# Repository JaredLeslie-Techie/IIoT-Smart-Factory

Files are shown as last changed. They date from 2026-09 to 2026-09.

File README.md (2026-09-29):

# IIoT Smart Factory

An Industrial Internet of Things project connecting a physical ESP8266 plant to MQTT, Node-RED dashboards, and a browser-based factory simulation. The physical setup reads environmental sensors, handles local controls, drives a DC motor, and indicates robot state with two LEDs.

## System overview

```mermaid
flowchart TB
    HW["ESP8266: sensors, buttons, motor, LEDs"]
    MQ["HiveMQ Cloud MQTT broker"]
    NR["Node-RED monitoring dashboards"]
    SIM["Browser factory simulation"]

    HW <-->|"MQTT over TLS"| MQ
    MQ -->|"Telemetry and state"| NR
    SIM <-->|"MQTT over WebSocket"| MQ
```

The firmware publishes measurements and button/state events. The browser simulation can publish remote commands to the broker. The supplied Node-RED export subscribes to MQTT messages and displays them; it contains no MQTT output node.

## Hardware

| Component | Purpose |
|---|---|
| NodeMCU ESP8266 | Wi-Fi controller and MQTT client |
| DHT11 | Temperature and humidity |
| LDR module | Light intensity |
| Four push buttons | Local robot and conveyor Start/Stop |
| L298N and DC motor | Conveyor drive |
| Yellow and blue LEDs | Robot operating and idle indication |
| Raspberry Pi 4 | Node-RED host used for the project |

| ESP8266 pin | Connection |
|---|---|
| D0 / D1 | L298N motor inputs |
| D2 / D3 | Conveyor Start / Stop buttons |
| D4 / D5 | Robot Start / Stop buttons |
| D6 / D7 | Yellow robot-on / blue robot-off LEDs |
| D8 | DHT11 |
| A0 | LDR |

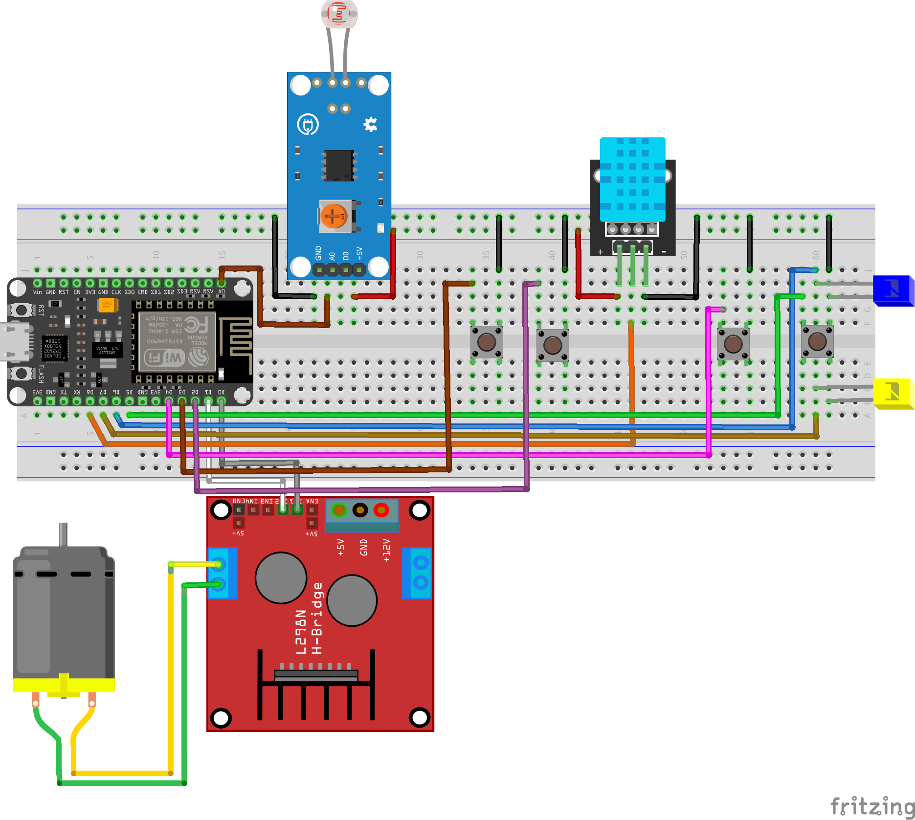
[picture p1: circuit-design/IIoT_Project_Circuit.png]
Fritzing circuit diagram


The complete editable Fritzing design and a PDF are in [`circuit-design/`](circuit-design/). The detailed pin table, flowcharts, and implementation notes are in the [technical notebook](documentation/IIoT_Smart_Factory_Documentation.ipynb).

## MQTT topics

The firmware publishes the following topics. Temperature, humidity, light intensity, and motor state are sent at a two-second interval; button events are sent when pressed.

| Topic | Value |
|---|---|
| `room/temperature` | Temperature in °C |
| `room/humidity` | Relative humidity in % |
| `room/LightIntensity` | Mapped light level, 0–100 |
| `room/MotorState` | `1` running, `0` stopped |
| `room/StartButton`, `room/StopButton` | Physical conveyor button events |
| `room/StartRobot`, `room/StopRobot` | Robot control events and status |

The firmware subscribes to these active command topics. It accepts `1`, `true`, `on`, `start`, or `pressed` as an active payload.

| Topic | Physical effect |
|---|---|
| `factory/room1/robot/start` | Yellow LED on, blue LED off |
| `factory/room1/robot/stop` | Yellow LED off, blue LED on |
| `room/StartButton` | Start the conveyor motor |
| `room/StopButton` | Stop the conveyor motor |

The Node-RED flow also **monitors** `factory/room1/conveyor/start` and `factory/room1/conveyor/stop` to update its dashboard state. It does not translate those messages into commands for the ESP8266. To control the physical conveyor, a remote client must publish to the `room/StartButton` and `room/StopButton` topics used by the firmware.

## Dashboard and project evidence

The Node-RED export has **Smart Factory**, **Actuators and Sensors**, and **Weather** pages. The Weather flow obtains external observations and alerts through the Bright Sky API and compares them with local DHT11 readings. Its ten-minute risk estimate is based on weather variables and alert conditions.

| Smart Factory monitoring | Sensors and actuators | Weather page |
|---|---|---|
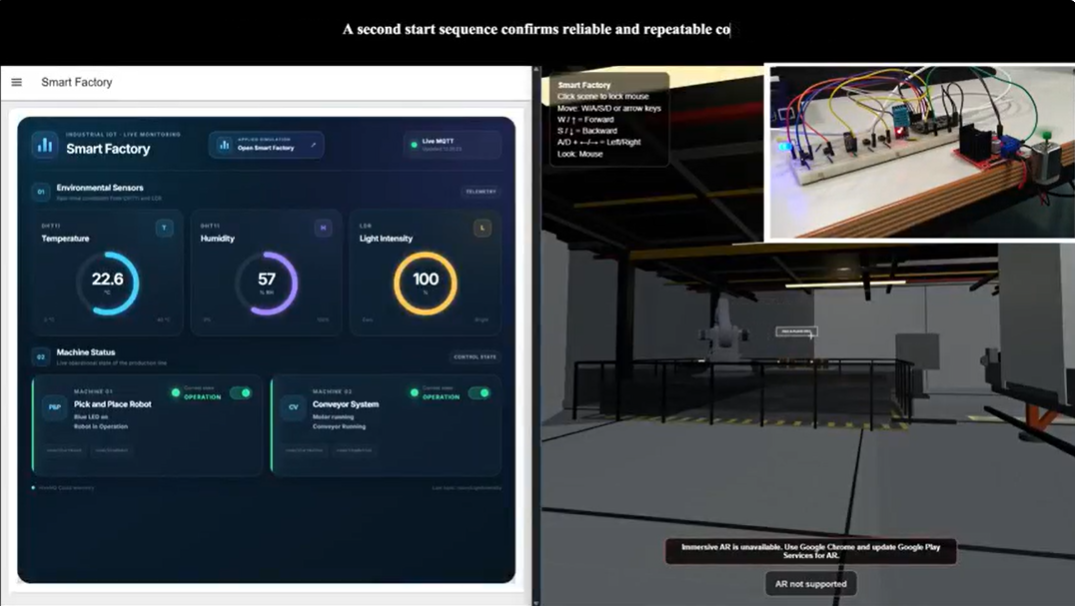
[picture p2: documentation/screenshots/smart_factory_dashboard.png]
Smart Factory dashboard
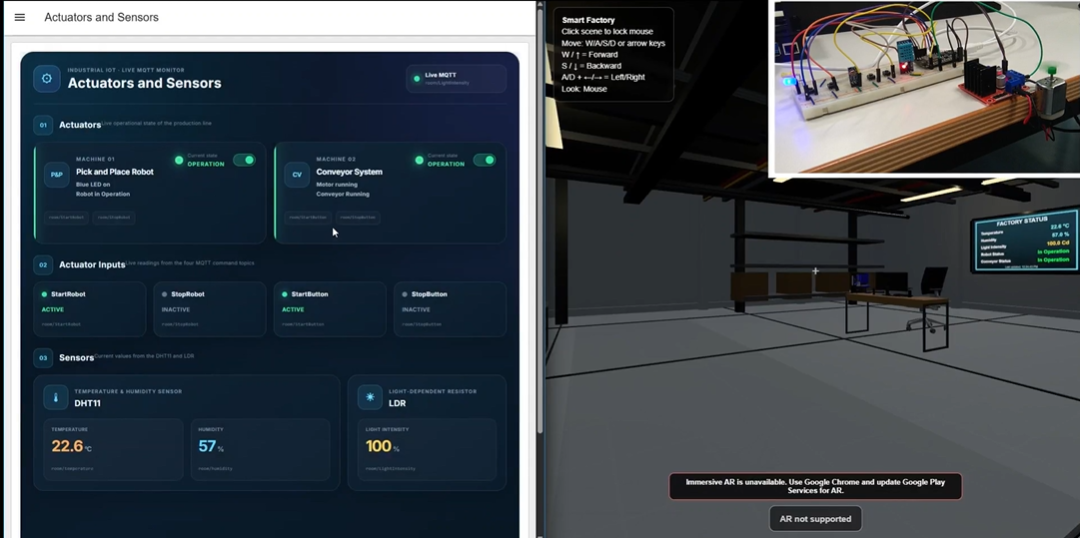
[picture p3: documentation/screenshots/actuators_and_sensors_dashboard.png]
Actuators and Sensors dashboard
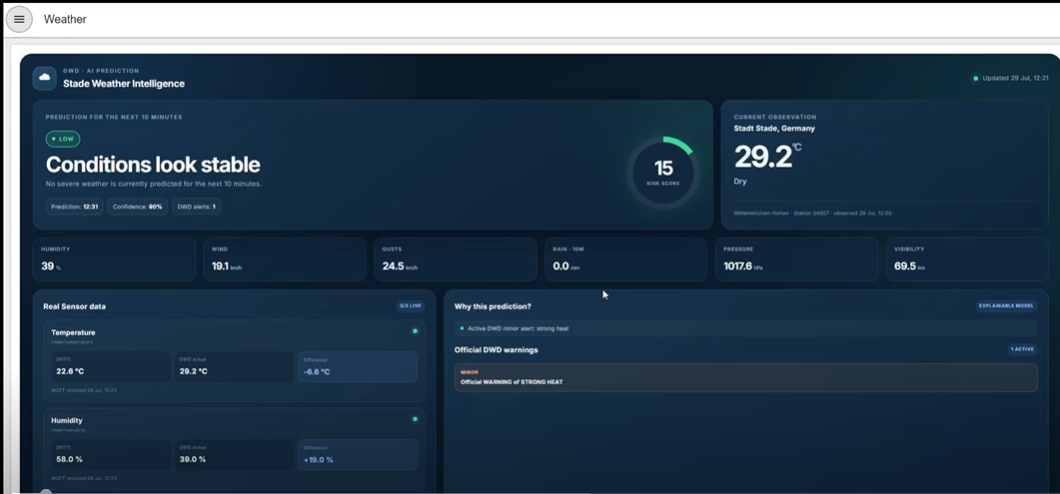
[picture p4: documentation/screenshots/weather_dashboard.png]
Weather dashboard
|  |  |  |

## Getting started

1. Open [`firmware/ESP8266_Smart_Factory/`](firmware/ESP8266_Smart_Factory/). Copy `secrets.example.h` to `secrets.h` in that folder and fill in your Wi-Fi SSID/password, HiveMQ username/password, and full broker hostname. Keep `secrets.h` local.
2. Install the ESP8266 Arduino board support and the `PubSubClient` and `DHT` libraries. Open `ESP8266_Smart_Factory.ino`, select your NodeMCU ESP8266 board, upload it, and use a Serial Monitor at **115200 baud**.
3. In Node-RED, import [`node-red/Smart_Factory_Flows.json`](node-red/Smart_Factory_Flows.json). Install the dashboard nodes indicated by the import if needed. Edit the seven MQTT broker configurations to use your broker hostname and add authentication locally; the exported hostname is a placeholder and credentials are not included. The configuration uses TLS on port **8883**.
4. Deploy the flows, then open the dashboard to view live messages. The Weather page also needs network access to the external weather API.

The browser simulation's source was not included in the supplied archive. It will be added after its connection settings can be reviewed; the firmware, Node-RED export, circuit design, and technical documentation are provided here.

## Security and implementation notes

- `.gitignore` excludes `secrets.h`, but check every file before manually uploading through GitHub's website. Node-RED stores credentials separately from this flow export; do not commit a Node-RED credentials file.
- The current ESP8266 sketch calls `espClient.setInsecure()`. MQTT traffic uses TLS, but this setting disables server certificate verification. Configure certificate verification before using the code in an untrusted or production environment.
- The ESP8266 D3, D4, and D8 pins affect boot configuration; the attached circuit must allow the correct levels during reset.

## Demonstration video

Watch the IIoT Smart Factory in operation, including the ESP8266 hardware, Node-RED dashboards, and browser simulation.

Watch the IIoT Smart Factory demonstration on YouTube (https://youtu.be/29-3qCWDQm4)

[▶ Watch the full demonstration on YouTube](https://youtu.be/29-3qCWDQm4)

Click the image or the link to play the video on YouTube.

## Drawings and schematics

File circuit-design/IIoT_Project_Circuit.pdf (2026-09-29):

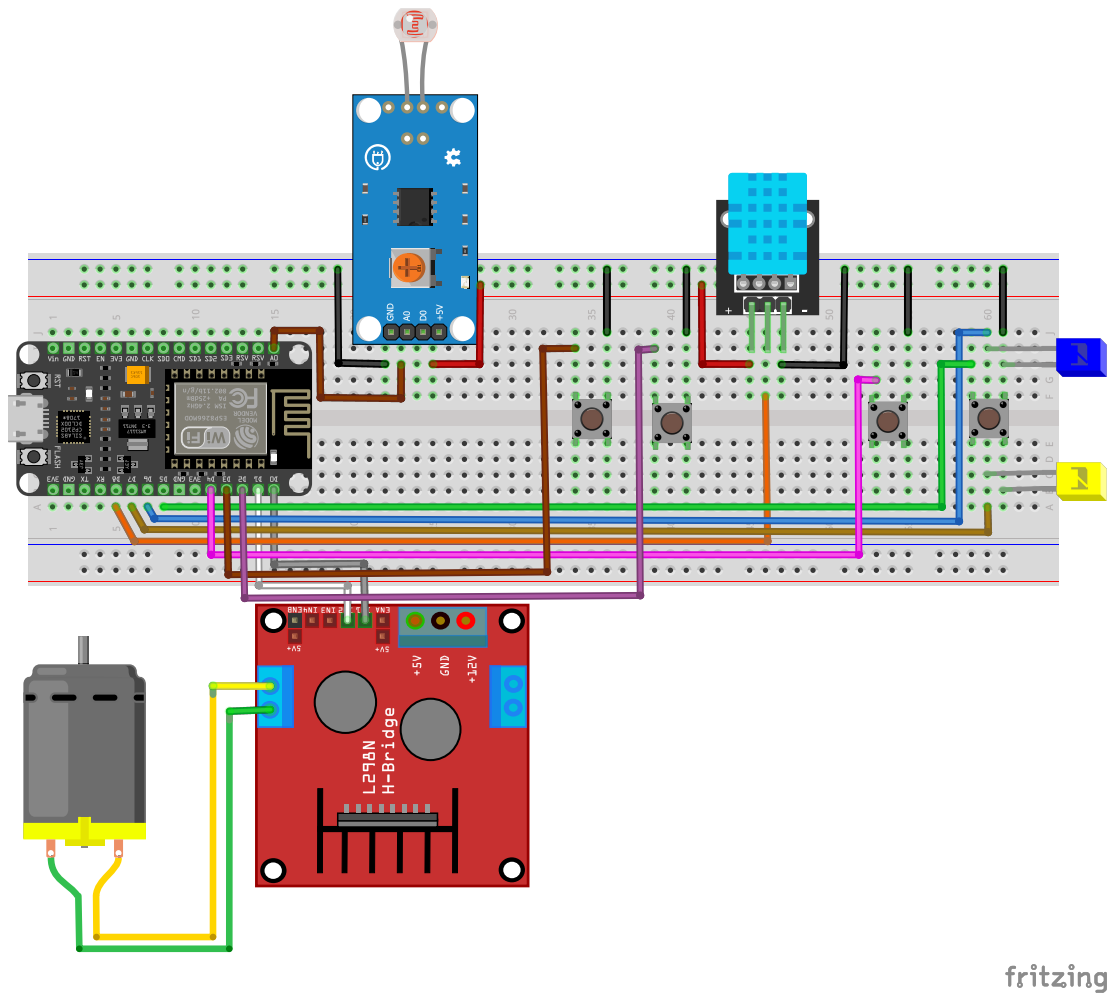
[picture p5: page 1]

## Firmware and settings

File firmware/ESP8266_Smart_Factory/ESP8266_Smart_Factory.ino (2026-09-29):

#include <ESP8266WiFi.h>
#include <WiFiClientSecure.h>
#include <PubSubClient.h>
#include <DHT.h>
#include "secrets.h"

#define DHT11_PIN D8
#define DHTTYPE DHT11

DHT dht(DHT11_PIN, DHTTYPE);

// Local credentials are defined in secrets.h (see secrets.example.h).
const char* ssid = WIFI_SSID;
const char* password = WIFI_PASSWORD;
const char* MQTT_username = MQTT_USERNAME;
const char* MQTT_password = MQTT_PASSWORD;
const char* mqtt_server = MQTT_SERVER;

// HiveMQ Cloud TLS on port 8883
const int mqtt_port = 8883;

const char* TOPIC_TEMPERATURE    = "room/temperature";
const char* TOPIC_HUMIDITY       = "room/humidity";
const char* TOPIC_MOTOR_STATE    = "room/MotorState";
const char* TOPIC_START_ROBOT    = "room/StartRobot";
const char* TOPIC_STOP_ROBOT     = "room/StopRobot";
const char* TOPIC_START_BUTTON   = "room/StartButton";
const char* TOPIC_STOP_BUTTON    = "room/StopButton";
const char* TOPIC_LIGHT_INTENSITY = "room/LightIntensity";

// MQTT command topics for remote control
const char* TOPIC_CMD_ROBOT_START    = "factory/room1/robot/start";
const char* TOPIC_CMD_ROBOT_STOP     = "factory/room1/robot/stop";
const char* TOPIC_CMD_CONVEYOR_START = "room/StartButton";
const char* TOPIC_CMD_CONVEYOR_STOP  = "room/StopButton";

// Secure client for TLS connection to HiveMQ Cloud
WiFiClientSecure espClient;
PubSubClient client(espClient);

// L298N Motor A
int motor1Pin1 = D0;
int motor1Pin2 = D1;

// PushButtons
int startButton = D2;
int stopButton = D3;

// LDR & ROBOT
const int ldrPin = A0;
const int StartRobot = D4;
const int StopRobot = D5;
const int RobotOn = D6;     // Yellow LED: robot operating
const int RobotOff = D7;    // Blue LED: robot idle

// Motor state
bool motorRunning = false;

int lightintensity = 0;

// Timers for readings, publishing, and MQTT reconnection
unsigned long previousLdrMillis = 0;
unsigned long previousDhtPublishMillis = 0;
unsigned long previousMqttReconnectMillis = 0;

const unsigned long ldrInterval = 500;
const unsigned long dhtPublishInterval = 2000;
const unsigned long reconnectInterval = 5000;

unsigned long lastStartButtonTime = 0;
unsigned long lastStopButtonTime = 0;
unsigned long lastStartRobotTime = 0;
unsigned long lastStopRobotTime = 0;
const unsigned long debounceDelay = 50;

int previousStartButtonState = HIGH;
int previousStopButtonState = HIGH;
int previousStartRobotState = HIGH;
int previousStopRobotState = HIGH;

// Returns true for common MQTT ON payloads.
bool mqttCommandIsTrue(const byte* payload, unsigned int length) {
  String command;
  command.reserve(length);

  for (unsigned int i = 0; i < length; i++) {
    command += (char)payload[i];
  }

  command.trim();
  command.toLowerCase();

  return command == "true" || command == "1" || command == "on" ||
         command == "start" || command == "pressed";
}

void mqttCallback(char* topic, byte* payload, unsigned int length) {
  bool activated = mqttCommandIsTrue(payload, length);

  Serial.print("MQTT received [");
  Serial.print(topic);
  Serial.print("]: ");
  for (unsigned int i = 0; i < length; i++) {
    Serial.print((char)payload[i]);
  }
  Serial.println();

  // Only an activated/true command changes an output.
  if (!activated) {
    return;
  }

  if (strcmp(topic, TOPIC_CMD_ROBOT_START) == 0) {
    digitalWrite(RobotOff, LOW);
    digitalWrite(RobotOn, HIGH);

    publishMessage(TOPIC_START_ROBOT, "1");
    publishMessage(TOPIC_STOP_ROBOT, "0");
  }
  else if (strcmp(topic, TOPIC_CMD_ROBOT_STOP) == 0) {
    digitalWrite(RobotOff, HIGH);
    digitalWrite(RobotOn, LOW);

    publishMessage(TOPIC_STOP_ROBOT, "1");
    publishMessage(TOPIC_START_ROBOT, "0");
  }
  else if (strcmp(topic, TOPIC_CMD_CONVEYOR_START) == 0) {
    motorRunning = true;

    publishMessage(TOPIC_MOTOR_STATE, "1");
  }
  else if (strcmp(topic, TOPIC_CMD_CONVEYOR_STOP) == 0) {
    motorRunning = false;

    publishMessage(TOPIC_MOTOR_STATE, "0");
  }
}

// Function to handle connection to the Wi-Fi network
void setup_wifi() {
  Serial.println();
  Serial.print("Connecting to ");
  Serial.println(ssid);

  WiFi.begin(ssid, password);

  while (WiFi.status() != WL_CONNECTED) {
    delay(500);
    Serial.print(".");
  }

  Serial.println("");
  Serial.println("Wi-Fi connected!");
  Serial.print("IP address: ");
  Serial.println(WiFi.localIP());
}

// Non-blocking MQTT reconnect attempt
void reconnect() {
  if (client.connected()) {
    return;
  }

  unsigned long currentMillis = millis();
  if (currentMillis - previousMqttReconnectMillis >= reconnectInterval) {
    previousMqttReconnectMillis = currentMillis;

    Serial.print("Attempting MQTT connection...");

    // Pass username and password - HiveMQ Cloud requires authentication
    String clientId = "NodeMCUClient-" + String(ESP.getChipId(), HEX);
    if (client.connect(clientId.c_str(), MQTT_username, MQTT_password)) {
      Serial.println("connected");

      bool robotStartSubscribed = client.subscribe(TOPIC_CMD_ROBOT_START);
      bool robotStopSubscribed = client.subscribe(TOPIC_CMD_ROBOT_STOP);
      bool conveyorStartSubscribed = client.subscribe(TOPIC_CMD_CONVEYOR_START);
      bool conveyorStopSubscribed = client.subscribe(TOPIC_CMD_CONVEYOR_STOP);

      Serial.print("Robot start subscription: ");
      Serial.println(robotStartSubscribed ? "OK" : "FAILED");
      Serial.print("Robot stop subscription: ");
      Serial.println(robotStopSubscribed ? "OK" : "FAILED");
      Serial.print("Conveyor start subscription: ");
      Serial.println(conveyorStartSubscribed ? "OK" : "FAILED");
      Serial.print("Conveyor stop subscription: ");
      Serial.println(conveyorStopSubscribed ? "OK" : "FAILED");
    } else {
      Serial.print("failed, rc=");
      Serial.print(client.state());
      Serial.println(" trying again in 5 seconds");
    }
  }
}

void publishMessage(const char* topic, const char* payload) {
  if (client.connected()) {
    client.publish(topic, payload);
  }
}

void publishFloatValue(const char* topic, float value) {
  if (!client.connected()) {
    return;
  }

  char valueStr[12];
  dtostrf(value, 6, 2, valueStr);
  client.publish(topic, valueStr);
}

void publishIntValue(const char* topic, int value) {
  if (!client.connected()) {
    return;
  }

  char valueStr[12];
  snprintf(valueStr, sizeof(valueStr), "%d", value);
  client.publish(topic, valueStr);
}

void publishPeriodicStates() {
  if (!client.connected()) {
    return;
  }

  publishMessage(TOPIC_MOTOR_STATE, motorRunning ? "1" : "0");
  publishIntValue(TOPIC_LIGHT_INTENSITY, lightintensity);
}

void setup() {
  Serial.begin(115200);

  // ROBOT CONTROL
  pinMode(StartRobot, INPUT_PULLUP);
  pinMode(StopRobot, INPUT_PULLUP);

  pinMode(RobotOff, OUTPUT);
  pinMode(RobotOn, OUTPUT);

  digitalWrite(RobotOff, LOW);
  digitalWrite(RobotOn, LOW);

  // Motor
  pinMode(motor1Pin1, OUTPUT);
  pinMode(motor1Pin2, OUTPUT);

  // Button pins with internal pull-ups
  pinMode(startButton, INPUT_PULLUP);
  pinMode(stopButton, INPUT_PULLUP);

  // Start with motor off
  digitalWrite(motor1Pin1, LOW);
  digitalWrite(motor1Pin2, LOW);

  // Initialize DHT and MQTT after the motor outputs are off
  dht.begin();
  setup_wifi();

  espClient.setInsecure();

  client.setServer(mqtt_server, mqtt_port);
  client.setCallback(mqttCallback);
}

void loop() {
  if (!client.connected()) {
    reconnect();
  }
  client.loop();

  unsigned long currentMillis = millis();

  // Read the LDR at the configured interval
  if (currentMillis - previousLdrMillis >= ldrInterval) {
    previousLdrMillis = currentMillis;

    int ldrValue = analogRead(ldrPin);

    // Mapping the LDR value to 0–100
    lightintensity = map(ldrValue, 120, 890, 0, 100);

    // Prevent values outside the range
    lightintensity = constrain(lightintensity, 0, 100);

    Serial.print("Light Intensity: ");
    Serial.println(lightintensity);
  }

  // Read button states (Active LOW because of INPUT_PULLUP)
  int currentStartButtonState = digitalRead(startButton);
  int currentStopButtonState = digitalRead(stopButton);

  // StartButton publishes immediately only on a new press
  if (currentStartButtonState == LOW && previousStartButtonState == HIGH && currentMillis - lastStartButtonTime >= debounceDelay) {
    lastStartButtonTime = currentMillis;
    motorRunning = true;

    publishMessage(TOPIC_START_BUTTON, "1");
    publishMessage(TOPIC_MOTOR_STATE, "1");
    client.loop();
  }

  // StopButton publishes immediately only on a new press
  if (currentStopButtonState == LOW && previousStopButtonState == HIGH && currentMillis - lastStopButtonTime >= debounceDelay) {
    lastStopButtonTime = currentMillis;
    motorRunning = false;

    publishMessage(TOPIC_STOP_BUTTON, "1");
    publishMessage(TOPIC_MOTOR_STATE, "0");
    client.loop();
  }

  previousStartButtonState = currentStartButtonState;
  previousStopButtonState = currentStopButtonState;

  // Control the motor based on state
  if (motorRunning) {
    digitalWrite(motor1Pin1, HIGH);
    digitalWrite(motor1Pin2, LOW);
  } else {
    digitalWrite(motor1Pin1, LOW);
    digitalWrite(motor1Pin2, LOW);
  }

  int currentStartRobotState = digitalRead(StartRobot);
  int currentStopRobotState = digitalRead(StopRobot);

  // StartRobot activates the yellow LED and publishes on a new press
  if (currentStartRobotState == LOW && previousStartRobotState == HIGH && currentMillis - lastStartRobotTime >= debounceDelay) {
    lastStartRobotTime = currentMillis;
    digitalWrite(RobotOff, LOW);   // Blue OFF
    digitalWrite(RobotOn, HIGH);   // Yellow ON

    publishMessage(TOPIC_START_ROBOT, "1");
    publishMessage(TOPIC_STOP_ROBOT, "0");
    client.loop();
  }

  // StopRobot activates the blue LED and publishes on a new press
  if (currentStopRobotState == LOW && previousStopRobotState == HIGH && currentMillis - lastStopRobotTime >= debounceDelay) {
    lastStopRobotTime = currentMillis;
    digitalWrite(RobotOff, HIGH);  // Blue ON
    digitalWrite(RobotOn, LOW);    // Yellow OFF

    publishMessage(TOPIC_STOP_ROBOT, "1");
    publishMessage(TOPIC_START_ROBOT, "0");
    client.loop();
  }

  previousStartRobotState = currentStartRobotState;
  previousStopRobotState = currentStopRobotState;

  // Read DHT and publish periodic sensor values
  if (currentMillis - previousDhtPublishMillis >= dhtPublishInterval) {
    previousDhtPublishMillis = currentMillis;

    float Temperature = dht.readTemperature();
    float Humidity = dht.readHumidity();

    if (isnan(Temperature) || isnan(Humidity)) {
      Serial.println(F("Failed to read from DHT sensor!"));
    } else {
      Serial.print("Temperature = ");
      Serial.print(Temperature);
      Serial.println("°C ");
      Serial.print("Humidity = ");
      Serial.println(Humidity);

      publishFloatValue(TOPIC_TEMPERATURE, Temperature);
      publishFloatValue(TOPIC_HUMIDITY, Humidity);
    }

    // These publish periodically. StartButton and StopButton are NOT published here.
    // They only publish inside their button-press input blocks above.
    publishPeriodicStates();
  }
}
